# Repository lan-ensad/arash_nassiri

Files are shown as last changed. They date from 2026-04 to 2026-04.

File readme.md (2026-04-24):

# Ambilight -- Arash Nassiri

Systeme ambilight temps reel : un script Python analyse les bords d'une video, extrait les couleurs dominantes et les envoie en **UDP via WiFi** a un microcontroleur Seeed XIAO ESP32-C6 qui pilote **2 chaines** de 260 LEDs WS2812 (520 LEDs au total, 8.67 m, 60 pixels/m).

L'ESP32 et l'ordinateur de diffusion sont connectes sur un **reseau WiFi ferme** dedie. L'ESP32 est monte au milieu du bas ; les 2 chaines partent de ce point central vers la gauche et la droite, pour minimiser la longueur du fil data.

## Architecture

```
Source video (fichier ou capture HDMI via Cam Link)
    │
    ▼
Script Python (PC)  ──►  analyse des bords  ──►  traitement couleur  ──►  UDP (WiFi)
                         (zones.py)               (colors.py)             (udp_sender.py)
                                                                               │
                                                                               ▼
                                                                 Reseau WiFi ferme
                                                                               │
                                                                               ▼
                                                                      Firmware ESP32-C6
                                                                      (NeoPixelBus → WS2812)
                                                                               │
                                                                               ▼
                                                                      2 chaines de 260 LEDs
                                                                      (A = gauche, B = droite)
```

## Disposition physique

Vu depuis la position du spectateur, **face a l'ecran** :

```
         ┌─────────────────────────────────────────────────────┐
         │                     (haut : pas de ruban)           │
         │                                                     │
         │                                                     │
      ▲  │                                                     │  ▲
      │  │                                                     │  │
  150 │  │                                                     │  │ 150
  LEDs│  │                    [  E C R A N  ]                  │  │ LEDs
      │  │                                                     │  │
      │  │                                                     │  │
      │  └──────────┐                              ┌───────────┘  │
      │             │                              │              │
      └─ CHAINE A ──┤                              ├── CHAINE B ──┘
     (cote gauche)  │                              │   (cote droit)
                    │       ┌──────────────┐       │
      ◄─────────────┤       │  ESP32 + PCB │       ├─────────────►
       110 LEDs     └───────┤              ├───────┘    110 LEDs
       demi-bas             │    milieu    │            demi-bas
       gauche               └──────┬───────┘             droit
                                   │
                                   ▼
                            Alimentation 5 V
```

- **Chaine A** (260 LEDs) : cote **GAUCHE** du spectateur + demi-bas gauche
- **Chaine B** (260 LEDs) : cote **DROIT** du spectateur + demi-bas droit

Pour chaque chaine, le flux data part de l'ESP32, remonte le demi-bas (110 LEDs) puis le cote vertical (150 LEDs, du bas vers le haut).

## Chiffres cles

- **520 LEDs** WS2812 (2 chaines de 260, densite 60 px/m)
- **Alimentation** Mean Well LRS150F-5 (5 V / 30 A)
- **ESP32-C6** sortie D9 = chaine A (gauche), D10 = chaine B (droite)
- **Level shifter** SN74HCT14N (3.3 V → 5 V) entre ESP32 et rubans
- **Protocole** UDP port 4210, 2 paquets/frame (785 o chacun), ~47 KB/s a 30 fps

## Structure du projet

```
arash_nassiri/
├── readme.md               Ce fichier -- documentation generale
│
├── Firmware/               Firmware ESP32-C6 (PlatformIO)
│   └── README.md           → Installation, flashage, protocole UDP, troubleshooting firmware
│
├── script/                 Script Python (cote ordinateur)
│   └── README.md           → Installation, configuration, utilisation, troubleshooting soft
│
├── kicad/                  Electronique (schema + BOM + cablage)
│   ├── README.md           → Dimensionnement, BOM, cablage, precautions electriques
│   └── ambilight_kicad/    Projet KiCad
│
├── test_videos/            Videos de test (generees par ffmpeg)
├── run.sh                  Lancement production (fullscreen + unclutter)
└── _devis/                 Documents administratifs (devis, factures)
```

## Documentation par composant

| Composant | Documentation | Concerne |
|---|---|---|
| Electronique | [kicad/README.md](kicad/README.md) | Dimensionnement, BOM, cablage, SN74HCT14N, alimentation |
| Firmware ESP32 | [Firmware/README.md](Firmware/README.md) | PlatformIO, WiFi, flashage, protocole UDP |
| Script Python | [script/README.md](script/README.md) | OpenCV, source video, pipeline couleur, parametres |

## Demarrage rapide

Ordre recommande pour une premiere mise en route :

1. **Electronique** : lire [kicad/README.md](kicad/README.md), fabriquer / cabler la partie power + level shifter + rubans
2. **Firmware** : remplir `Firmware/src/wifi_config.h` puis flasher (voir [Firmware/README.md](Firmware/README.md))
3. **Script Python** : installer le venv et configurer `script/config.py` (voir [script/README.md](script/README.md))
4. **Lancer** : `./run.sh` depuis la racine (ou configurer le service systemd, section suivante)

Pour **tester le pipeline Python sans materiel** (loopback UDP) : voir la section Troubleshooting dans [script/README.md](script/README.md).

## Lancement automatique au boot (service systemd user)

Pour une installation permanente. Recommande quand la source video est externe (Cam Link) et `headless = True` dans `script/config.py` -- aucune session graphique requise.

`run.sh` integre deja l'attente reseau (ping de la passerelle par defaut, max 30 s) et une rotation simple des logs au demarrage : aucune modification requise avant installation.

### Prerequis a verifier dans `script/config.py`

| Parametre | Valeur recommandee | Raison |
|---|---|---|
| `headless` | `True` | Pas de session graphique sous systemd user (sauf si `DISPLAY` configure dans l'unit) |
| `terminal_preview` | `False` | Pas de terminal → les codes ANSI du preview polluent le fichier de log |
| `dry_run` | `False` | Sinon aucun paquet UDP n'est envoye |
| `video_path` / `camera_index` | source reelle | `video_path` est resolu relativement a `script/` |

IP ESP32 coherente entre `script/config.py` (`esp32_ip`) et `Firmware/src/wifi_config.h` (`LOCAL_IP_BYTES`).

### 1. Creer le service

Fichier `~/.config/systemd/user/ambilight.service` :

```ini
[Unit]
Description=Ambilight video capture and UDP send
After=network-online.target
Wants=network-online.target

[Service]
Type=simple
WorkingDirectory=/path/to/arash_nassiri
ExecStart=/path/to/arash_nassiri/run.sh
Restart=on-failure
RestartSec=5
Environment=PYTHONUNBUFFERED=1

# Double destination des logs :
#  - Fichier persistant (rotation geree par run.sh au demarrage, >10 Mo → archive timestampee, max 5 backups)
#  - Journal systemd user natif (rotation + compression gerees par journald)
StandardOutput=append:/path/to/arash_nassiri/logs/ambilight.log
StandardError=append:/path/to/arash_nassiri/logs/ambilight.log

[Install]
WantedBy=default.target
```

> Adapter les 3 chemins `/path/to/arash_nassiri/...` au chemin reel du projet. Le dossier `logs/` est cree automatiquement par `run.sh`.

### 2. Activer et demarrer

```bash
mkdir -p ~/.config/systemd/user
# (copier ambilight.service dans ce dossier)
systemctl --user daemon-reload
systemctl --user enable --now ambilight.service
```

### 3. Permettre le demarrage sans login utilisateur (lingering)

```bash
sudo loginctl enable-linger $USER
```

Sans cette ligne, le service ne demarre qu'apres connexion interactive.

### 4. Prerequis systeme

Utilisateur dans le groupe `video` pour acceder a la capture (Cam Link, webcam) :

```bash
sudo usermod -aG video $USER
# logout/login pour que le groupe prenne effet
```

### 5. Operer

```bash
# Etat
systemctl --user status ambilight.service

# Logs temps reel -- deux options equivalentes
tail -f logs/ambilight.log                          # fichier dedie
journalctl --user -u ambilight.service -f           # journal systemd

# Logs filtres
journalctl --user -u ambilight.service -p err       # erreurs uniquement
journalctl --user -u ambilight.service --since "1 hour ago"

# Cycle de vie
systemctl --user restart ambilight.service
systemctl --user stop    ambilight.service
```

### 6. Desinstaller le service

```bash
systemctl --user disable --now ambilight.service
rm -f ~/.config/systemd/user/ambilight.service
systemctl --user daemon-reload
sudo loginctl disable-linger $USER   # optionnel
```

## Reseau WiFi ferme

PC et ESP32 sur un reseau WiFi dedie (routeur/AP dedie ou hotspot du PC). Aucun trafic Internet ni autre appareil -- isolation garantit :
- Latence predictible (pas de contention)
- IP statique possible pour l'ESP32

**Config par defaut** :

| Parametre | Valeur | Fichier |
|---|---|---|
| IP ESP32 | `<IP_ESP>` | `script/config.py` + `Firmware/src/wifi_config.h` |
| Hostname ESP32 | `esp_ambilight` | `Firmware/src/wifi_config.h` |
| Port UDP | `4210` | `Firmware/src/wifi_config.h` |
| SSID / password | <SSID + PASS\> | `Firmware/src/wifi_config.h` |

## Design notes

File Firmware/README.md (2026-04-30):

# Firmware ESP32-C6

Reception des paquets UDP depuis le PC et pilotage des 2 chaines de LEDs WS2812 via NeoPixelBus (RMT).

## Prerequis

- [PlatformIO](https://platformio.org/) (extension VS Code ou CLI `pio`)
- Seeed XIAO ESP32-C6 branche en USB-C

## Configuration WiFi

Remplir les placeholders dans `src/wifi_config.h` avant de flasher :

```c
#define WIFI_SSID      "ambilight_net"       // SSID du reseau ferme
#define WIFI_PASSWORD  "mot_de_passe"

#define LOCAL_IP_BYTES    <IP_ESP>          // IP statique de l'ESP32 (format octets : a, b, c, d)
#define GATEWAY_IP_BYTES  <IP_ROUTEUR>      // IP du routeur/AP (format octets)
#define SUBNET_BYTES      255, 255, 255, 0
#define DNS_IP_BYTES      <IP_ROUTEUR>      // typiquement = gateway

#define UDP_PORT          4210
```

`LOCAL_IP_BYTES` doit correspondre a `esp32_ip` dans `script/config.py`.

## Flashage

### USB (premier flash, et recuperation)

```bash
pio run --target upload
pio device monitor    # optionnel : logs WiFi/UDP au boot
```

### OTA (flash sans fil via WiFi)

Le firmware embarque ArduinoOTA : a partir du moment ou il a ete flashe une
fois en USB, les flashs suivants peuvent se faire via le reseau.

**Pre-requis machine hote** : autoriser l'ESP32 a initier des connexions
TCP entrantes (sinon UFW/firewall bloque le retour TCP de l'OTA et `espota`
fait `Authenticating...OK` puis `No response from device`) :

```bash
sudo ufw allow from 192.168.8.50    # IP de l'ESP32 (LOCAL_IP_BYTES)
```

**Flash OTA** :

```bash
pio run -e seeed_xiao_esp32c6_ota -t upload
```

L'environnement `seeed_xiao_esp32c6_ota` defini dans `platformio.ini`
contient `--host_ip=192.168.8.202` (IP de la machine hote sur le subnet
192.168.8.x). Mettre a jour cette valeur si l'IP de la machine change
(DHCP) -- une reservation DHCP cote routeur est plus robuste a terme.

## Indicateurs visuels au boot

La 1re LED de chaque chaine sert d'indicateur :

| Couleur | Etat |
|---|---|
| **Jaune** | Connexion WiFi en cours |
| **Verte** (500 ms) | Connexion etablie, UDP en ecoute |
| **Noir** | En attente des paquets du PC |

## Protocole UDP

**2 paquets UDP par frame** (un par chaine), envoyes en rafale par le PC. Chaque paquet fait 785 octets :

| Octet | Contenu |
|---|---|
| 0 | `0xAA` (magic start) |
| 1 | `chain_id` (0 = chaine A gauche, 1 = chaine B droite) |
| 2 -- 3 | `seq_num` (uint16 big-endian) |
| 4 -- 783 | R, G, B pour chaque LED (260 x 3 = 780 octets) |
| 784 | `0x55` (magic end) |

**Taille totale par frame** : 2 x 785 = **1570 octets/frame** (vs MTU 1500 → aucune fragmentation IP au niveau paquet individuel).

**Bande passante a 30 fps** : 47 KB/s = ~376 kbps. Tres confortable meme en 2,4 GHz.

**Gestion cote firmware** (voir `src/main.cpp`) :
- `seq_num` : le firmware ignore les paquets dont le seq est plus ancien que le dernier recu (protection contre reordering UDP, rare en LAN)
- **Magic bytes** : `0xAA` / `0x55` verifies, sinon paquet ignore
- `chain_id 0 ou 1` : route le RGB data vers `stripA` (D9) ou `stripB` (D10). Chaque chaine est rafraichie des que son paquet arrive (pas de sync inter-chaines)
- `MAX_BRIGHTNESS` (defaut 230, soit ~90%) : applique une limite globale de luminosite pour proteger l'alimentation

## Pins utilises

| GPIO | Role |
|---|---|
| D9 | Signal data chaine A (gauche, 260 LEDs) |
| D10 | Signal data chaine B (droite, 260 LEDs) |

Voir [kicad/README.md](../kicad/README.md) pour le cablage complet (level shifter SN74HCT14N, resistances 330 ohm, decouplage).

## Structure des fichiers

```
Firmware/
├── platformio.ini              Configuration PlatformIO (board, framework, libs)
├── src/
│   ├── main.cpp                Reception UDP + pilotage NeoPixel (2 chaines)
│   └── wifi_config.h           Credentials WiFi + IP statique (a remplir)
├── include/                    Headers additionnels (vide par defaut)
├── lib/                        Bibliotheques locales (vide par defaut)
└── test/                       Tests (vide par defaut)
```

## Troubleshooting

### Freezes periodiques (~500 ms toutes les 2-3 s)

**Cause** : WiFi power-save du ESP32-C6 -- il wake seulement aux beacons DTIM, les paquets UDP s'accumulent sur l'AP puis sont livres en rafale.

**Fix** (deja applique dans `src/main.cpp`) : apres `WiFi.begin(...)`, desactiver le modem-sleep :
```cpp
WiFi.setSleep(false);
```

Si les freezes persistent malgre ce fix :

- **Canal WiFi encombre** -- force un canal libre (1, 6 ou 11) sur l'AP
- **Inactivite WiFi** -- ajouter apres `udp.begin(UDP_PORT)` :
  ```cpp
  esp_wifi_set_inactive_time(WIFI_IF_STA, 10);
  ```

### Aucun paquet recu (1re LED reste noire apres boot)

Verifier dans l'ordre :

1. **WiFi connecte** ? La 1re LED doit passer par jaune puis verte au boot. Si elle reste jaune, le WiFi n'a pas connecte : verifier SSID/password dans `wifi_config.h`.
2. **IP coherente** ? `LOCAL_IP_BYTES` doit etre dans le sous-reseau du routeur (pas de conflit avec un autre appareil). `esp32_ip` cote Python doit etre identique.
3. **Paquets envoyes par le PC** ? Cote PC :
   ```bash
   sudo tcpdump -i any -n 'udp port 4210'
   ```
   Doit montrer des paquets sortants du PC toutes les 33 ms (~30 fps).
4. **PC et ESP32 sur le meme reseau WiFi** ? Si le PC est en ethernet et l'ESP32 en WiFi, le routeur doit faire le pont entre les deux interfaces.

### LEDs erratiques / clignotent au hasard

Probleme electronique (GND, level shifter, longueur data). Voir [kicad/README.md](../kicad/README.md).

### Reduire la luminosite pour proteger l'alim

Dans `src/main.cpp`, ajuster :
```cpp
#define MAX_BRIGHTNESS  230   // 255 = aucune limite, 192 = 75%, 128 = 50%
```

Avec 520 LEDs et une PSU 30 A :
- 255 (100%) → 31.2 A max (depasse legerement le nominal de la PSU)
- 230 (~90%) → 28 A max (marge de securite)
- 192 (~75%) → 23 A max (tres confortable)

Un reflashage est necessaire apres modification.

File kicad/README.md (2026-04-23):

# Electronique -- Ambilight

Ce dossier contient le schema KiCad et toute la documentation electronique du projet (matiere, cablage, calculs, precautions).

Pour la partie logicielle (script Python + firmware ESP32) voir le [readme.md](../readme.md) a la racine.

## Vue d'ensemble

```
                                Mean Well LRS150F-5
                               ┌──────────────────┐
                       AC IN ──┤ L   N   ⏚        │
                               │                  │
                               │   +5V    GND     │
                               └───┬───────┬──────┘
                                   │       │
                              1000uF cap   │
                                   │       │
          ┌────────────────────────┼───────┼────────────────────────┐
          │  RAIL 5V (16AWG)       │       │  RAIL GND (16AWG)      │
          │                        │       │                        │
          │    ┌───────────────────┼───────┼──────────┐             │
          ▼    ▼                   ▼       ▼          ▼             ▼
     INJECTION 1              INJECTION 2        INJECTION 3
    (extremite gauche,        (milieu du bas,    (extremite droite,
     en haut du cote)         pres de l'ESP)     en haut du cote)
      100uF cap                100uF cap          100uF cap

    ┌─────────────────────────────────┬─────────────────────────────────┐
    │          CHAINE A (260 LEDs)    │          CHAINE B (260 LEDs)    │
    │  ┌────────────┬────────────┐    │    ┌────────────┬────────────┐  │
    │  │  GAUCHE    │  1/2 BAS   │    │    │  1/2 BAS   │  DROITE    │  │
    │  │  (150)     │  gauche    │    │    │  droite    │  (150)     │  │
    │  │  bas→haut  │  (110)     │    │    │  (110)     │  bas→haut  │  │
    │  │            │  gauche ←  │◄DIN│DIN►│  → droite  │            │  │
    │  │   DOUT ←── │ ← ─────────│    │    │────────── →│ ──► DOUT   │  │
    │  └────────────┴────────────┘    │    └────────────┴────────────┘  │
    └─────────────────────────────────┴─────────────────────────────────┘
                                 ▲       ▲
                    330 ohm ─────┤       ├──── 330 ohm
                                 │       │
                         data 5V │       │ data 5V (< 30 cm, 22AWG)
                          pin 4  │       │ pin 10
                    ┌────────────┴───────┴─────────────┐
                    │  SN74HCT14N (hex Schmitt inv.)   │
                    │                                  │
                    │  Chaine A : pin 1 → pin 2,       │
                    │             pin 3 → pin 4        │
                    │  Chaine B : pin 13 → pin 12,     │
                    │             pin 11 → pin 10      │
                    │                                  │
                    │  VCC = pin 14 (+5V) + 100nF      │
                    │  GND = pin 7                     │
                    │  entrees NC (5, 9) → GND         │
                    └──────▲──────────────▲────────────┘
                           │ pin 1        │ pin 13
                           │ data A 3.3V  │ data B 3.3V
                    ┌──────┴──────────────┴────────────┐
                    │  XIAO ESP32-C6                   │
                    │     D9 ─(chaine A gauche)        │
                    │    D10 ─(chaine B droite)        │
                    │    USB ← 5V (alim seule,         │
                    │          chargeur ou powerbank)  │
                    │    WiFi ◄─── UDP (port 4210)     │
                    └─────────────────────▲────────────┘
                                          │ reseau WiFi ferme dedie
                                          │
                                   ┌──────┴───────┐
                                   │  PC (Python) │
                                   │  udp_sender  │
                                   └──────────────┘
```

## Dimensionnement

### Installation

| Cote | Longueur |
|---|---|
| Bas | 368 cm |
| Droite | 250 cm |
| Gauche | 250 cm |
| **Total** | **868 cm = 8.68 m** |

### LEDs

Densite du ruban : **60 pixels/m**

| Cote | Longueur | LEDs |
|---|---|---|
| Bas | 3.67 m | 3.67 x 60 = **220** (110 + 110, symetrique) |
| Droite | 2.50 m | 2.50 x 60 = **150** |
| Gauche | 2.50 m | 2.50 x 60 = **150** |
| **Total** | **8.67 m** | **520 LEDs** |

Le bas est ramene de 221 a **220 LEDs** pour une **repartition symetrique** (110 par demi-cote). Le gain physique est de 1,67 cm, negligeable visuellement.

### Repartition en 2 chaines

L'ESP32 est positionne au **milieu du bas**. Deux chaines de LEDs partent de ce point central vers l'exterieur, pilotees chacune par un GPIO different :

| Chaine | GPIO | Trajet | LEDs |
|---|---|---|---|
| **A** (gauche) | D9 | demi-bas milieu → gauche, puis cote gauche bas → haut | 110 + 150 = **260** |
| **B** (droite) | D10 | demi-bas milieu → droite, puis cote droit bas → haut | 110 + 150 = **260** |

Avantages vs une seule chaine de 521 LEDs :
- Fil data 10 fois plus court (< 30 cm au lieu de ~1,85 m vers un coin)
- Rafraichissement LED plus rapide (2 chaines en parallele, ~260 LEDs chacune au lieu de 521)
- Ligne data moins sensible aux perturbations

### Puissance

Chaque LED WS2812 consomme au maximum 60 mA a 5 V (20 mA par canal R, G, B a pleine intensite).

| Scenario | Courant par LED | Courant total | Puissance (5 V) |
|---|---|---|---|
| Maximum (blanc 100%) | 60 mA | 520 x 60 mA = **31.2 A** | **156.0 W** |
| Utilisation typique ambilight (~30%) | ~20 mA | 520 x 20 mA = **10.4 A** | **52.0 W** |

**Alimentation choisie** : 1x Mean Well LRS150F-5 -- 5 V / 30 A (150 W).

> 30 A couvre le maximum theorique (31.2 A) a ~96%. En pratique l'ambilight ne
> depasse jamais le blanc pur simultane sur toutes les LEDs ; le budget typique
> (~10 A) laisse une large marge. Si un contenu pousse ponctuellement au-dela,
> la LRS150F-5 tolere des pics courts a 110% (33 A).

## Cablage de l'ESP32-C6

| Broche ESP32-C6 | Connexion | Note |
|---|---|---|
| USB-C ou pad 5V | 5 V depuis la PSU via Wago ou regulateur | Alim seule — les donnees passent par WiFi |
| D9 | Level shifter IN chaine A (pin 1) | Signal data chaine A (gauche, 260 LEDs) |
| D10 | Level shifter IN chaine B (pin 13) | Signal data chaine B (droite, 260 LEDs) |
| GND | GND commun (PSU + level shifter) | **Obligatoire** |
| WiFi (integre) | Reseau ferme dedie | Reception UDP du PC |

> **Decouplage ESP32** : placer 22 uF electrolytique + 100 nF ceramique en parallele sur le rail 5 V au plus pres du VBUS, pour filtrer le bruit HF genere par les 520 LEDs qui commutent a 800 kHz.

## Cablage du level shifter SN74HCT14N

Boitier DIP-14 (6 inverseurs Schmitt trigger independants). On utilise **4 portes** (2 cascades de 2 inverseurs), une cascade par chaine. 2 portes restent inutilisees.

```
           ┌───U───┐
    1A  ──1┤       ├14──  VCC (+5 V)
    1Y  ──2┤       ├13──  6A  ← D10 (chaine B, 3.3V)
    2A  ──3┤       ├12──  6Y
    2Y  ──4┤       ├11──  5A
    3A  ──5┤       ├10──  5Y  → 330 ohm → chaine B DIN (5V)
    3Y  ──6┤       ├9──── 4A  (NC → GND)
    GND ──7┤       ├8──── 4Y  (NC)
           └───────┘
```

### Chaine A (gauche) -- cascade inverseurs 1 et 2

| Broche | Role | Connexion |
|---|---|---|
| 1 (1A) | Entree inverseur 1 | Signal 3.3 V depuis ESP32 **D9** |
| 2 (1Y) | Sortie inverseur 1 | Relier a la broche 3 |
| 3 (2A) | Entree inverseur 2 | Relier a la broche 2 |
| 4 (2Y) | Sortie inverseur 2 (5 V) | Resistance 330 ohm puis DIN chaine A |

### Chaine B (droite) -- cascade inverseurs 6 et 5

| Broche | Role | Connexion |
|---|---|---|
| 13 (6A) | Entree inverseur 6 | Signal 3.3 V depuis ESP32 **D10** |
| 12 (6Y) | Sortie inverseur 6 | Relier a la broche 11 |
| 11 (5A) | Entree inverseur 5 | Relier a la broche 12 |
| 10 (5Y) | Sortie inverseur 5 (5 V) | Resistance 330 ohm puis DIN chaine B |

### Portes inutilisees (inverseurs 3 et 4)

| Broche | Role | Connexion |
|---|---|---|
| 5 (3A), 9 (4A) | Entrees inutilisees | **Obligatoire : relier a GND** |
| 6 (3Y), 8 (4Y) | Sorties inutilisees | Laisser en l'air |

### Alimentation

| Broche | Connexion |
|---|---|
| 14 (VCC) | +5 V depuis la PSU |
| 7 (GND) | GND commun avec PSU et ESP32 |

**Decouplage** : condensateur 100 nF ceramique (marquage "104") entre broche 14 et broche 7, **au plus pres du chip** (pattes < 5 mm).

## Fichiers KiCad

Le projet KiCad complet est dans [ambilight_kicad/](ambilight_kicad/).

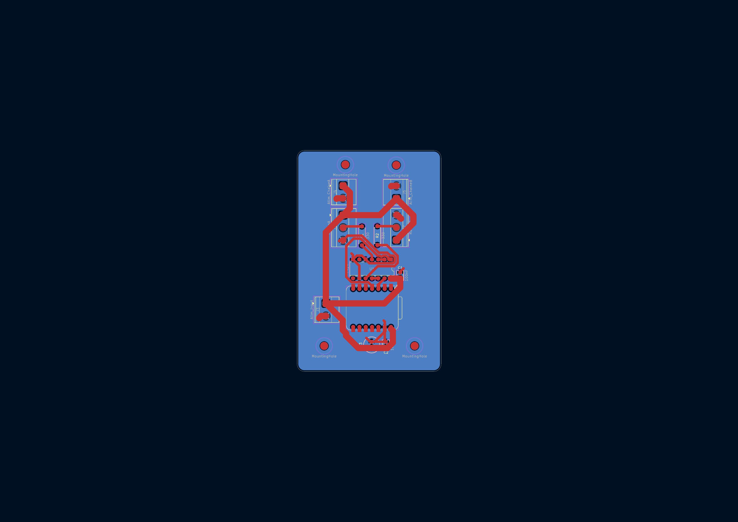
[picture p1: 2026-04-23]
kicad/ambilight_kicad/layout.jpg

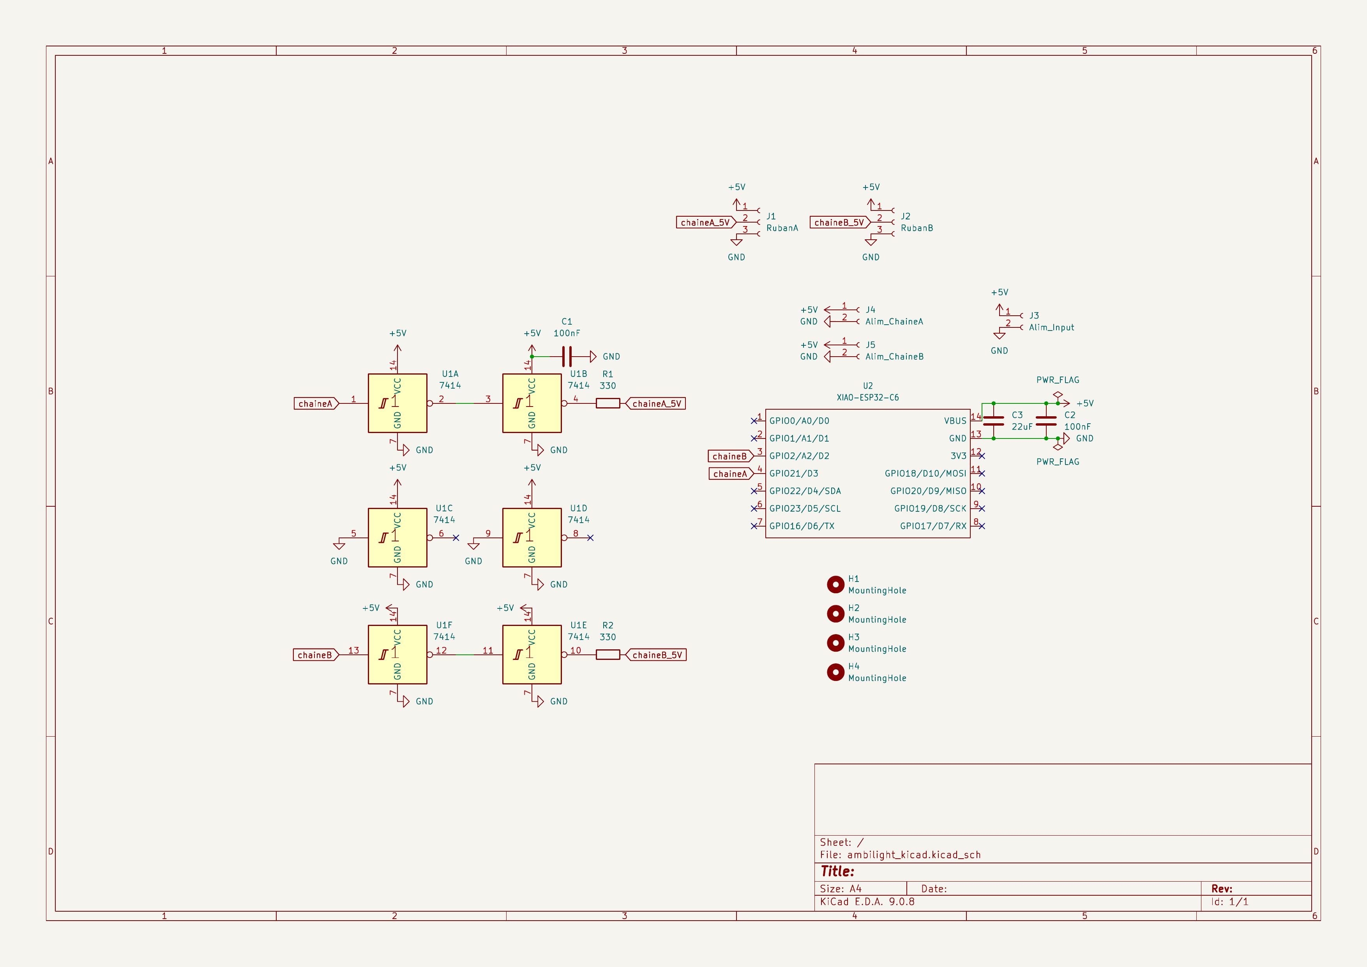
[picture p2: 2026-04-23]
kicad/ambilight_kicad/schem.jpg

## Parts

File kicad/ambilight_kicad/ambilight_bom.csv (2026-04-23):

Reference | Qty | Value | DNP | Exclude from BOM | Exclude from Board | Footprint | Datasheet
C1,C2 | 2 | 100nF |  |  |  | Capacitor_THT:C_Disc_D3.8mm_W2.6mm_P2.50mm | ~
C3 | 1 | 22uF |  |  |  | Capacitor_THT:C_Radial_D6.3mm_H7.0mm_P2.50mm | ~
H1,H2,H3,H4 | 4 | MountingHole |  | Excluded from BOM |  | MountingHole:MountingHole_3.2mm_M3 | ~
J1 | 1 | RubanA |  |  |  | TerminalBlock_Phoenix:TerminalBlock_Phoenix_MKDS-1,5-3-5.08_1x03_P5.08mm_Horizontal | ~
J2 | 1 | RubanB |  |  |  | TerminalBlock_Phoenix:TerminalBlock_Phoenix_MKDS-1,5-3-5.08_1x03_P5.08mm_Horizontal | ~
J3 | 1 | Alim_Input |  |  |  | TerminalBlock_Phoenix:TerminalBlock_Phoenix_MKDS-1,5-2-5.08_1x02_P5.08mm_Horizontal | ~
J4 | 1 | Alim_ChaineA |  |  |  | TerminalBlock_Phoenix:TerminalBlock_Phoenix_MKDS-1,5-2-5.08_1x02_P5.08mm_Horizontal | ~
J5 | 1 | Alim_ChaineB |  |  |  | TerminalBlock_Phoenix:TerminalBlock_Phoenix_MKDS-1,5-2-5.08_1x02_P5.08mm_Horizontal | ~
R1,R2 | 2 | 330 |  |  |  | Resistor_THT:R_Axial_DIN0207_L6.3mm_D2.5mm_P7.62mm_Horizontal | ~
U1 | 1 | 7414 |  |  |  | Package_DIP:DIP-14_W7.62mm
U2 | 1 | XIAO-ESP32-C6 |  |  |  | XIAO:XIAO-ESP32C6-DIP

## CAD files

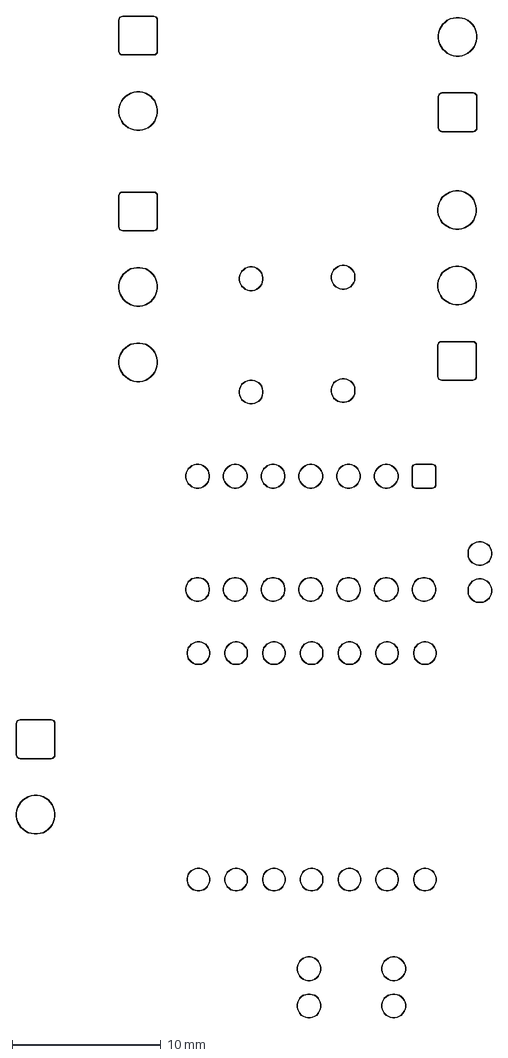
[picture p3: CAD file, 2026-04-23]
kicad/ambilight_kicad/gerber/ambilight_kicad-B_Cu.dxf
32.0 x 67.4 mm

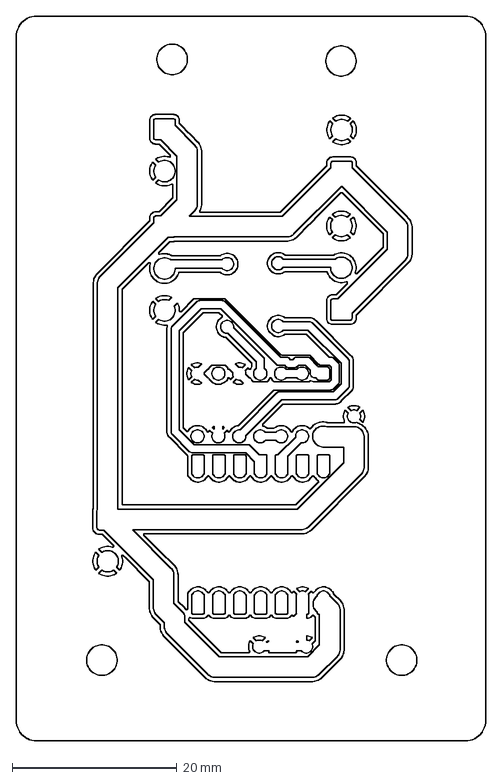
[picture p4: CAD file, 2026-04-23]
kicad/ambilight_kicad/gerber/ambilight_kicad-F_Cu.dxf
57.0 x 88.0 mm

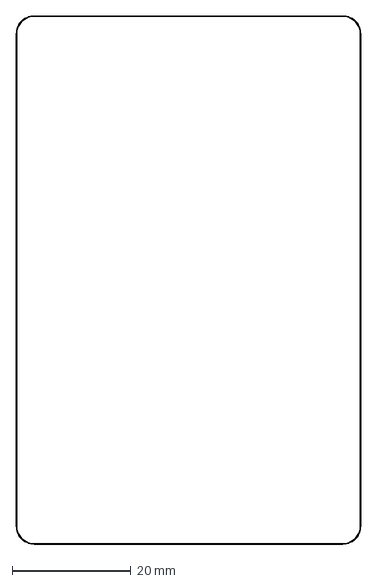
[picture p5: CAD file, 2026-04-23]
kicad/ambilight_kicad/gerber/ambilight_kicad-Edge_Cuts.dxf
58.0 x 89.0 mm

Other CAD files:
kicad/ambilight_kicad/gerber/ambilight_kicad-B_Mask.dxf
kicad/ambilight_kicad/gerber/ambilight_kicad-B_Paste.dxf
kicad/ambilight_kicad/gerber/ambilight_kicad-B_Silkscreen.dxf
kicad/ambilight_kicad/gerber/ambilight_kicad-F_Mask.dxf
kicad/ambilight_kicad/gerber/ambilight_kicad-F_Paste.dxf
kicad/ambilight_kicad/gerber/ambilight_kicad-F_Silkscreen.dxf

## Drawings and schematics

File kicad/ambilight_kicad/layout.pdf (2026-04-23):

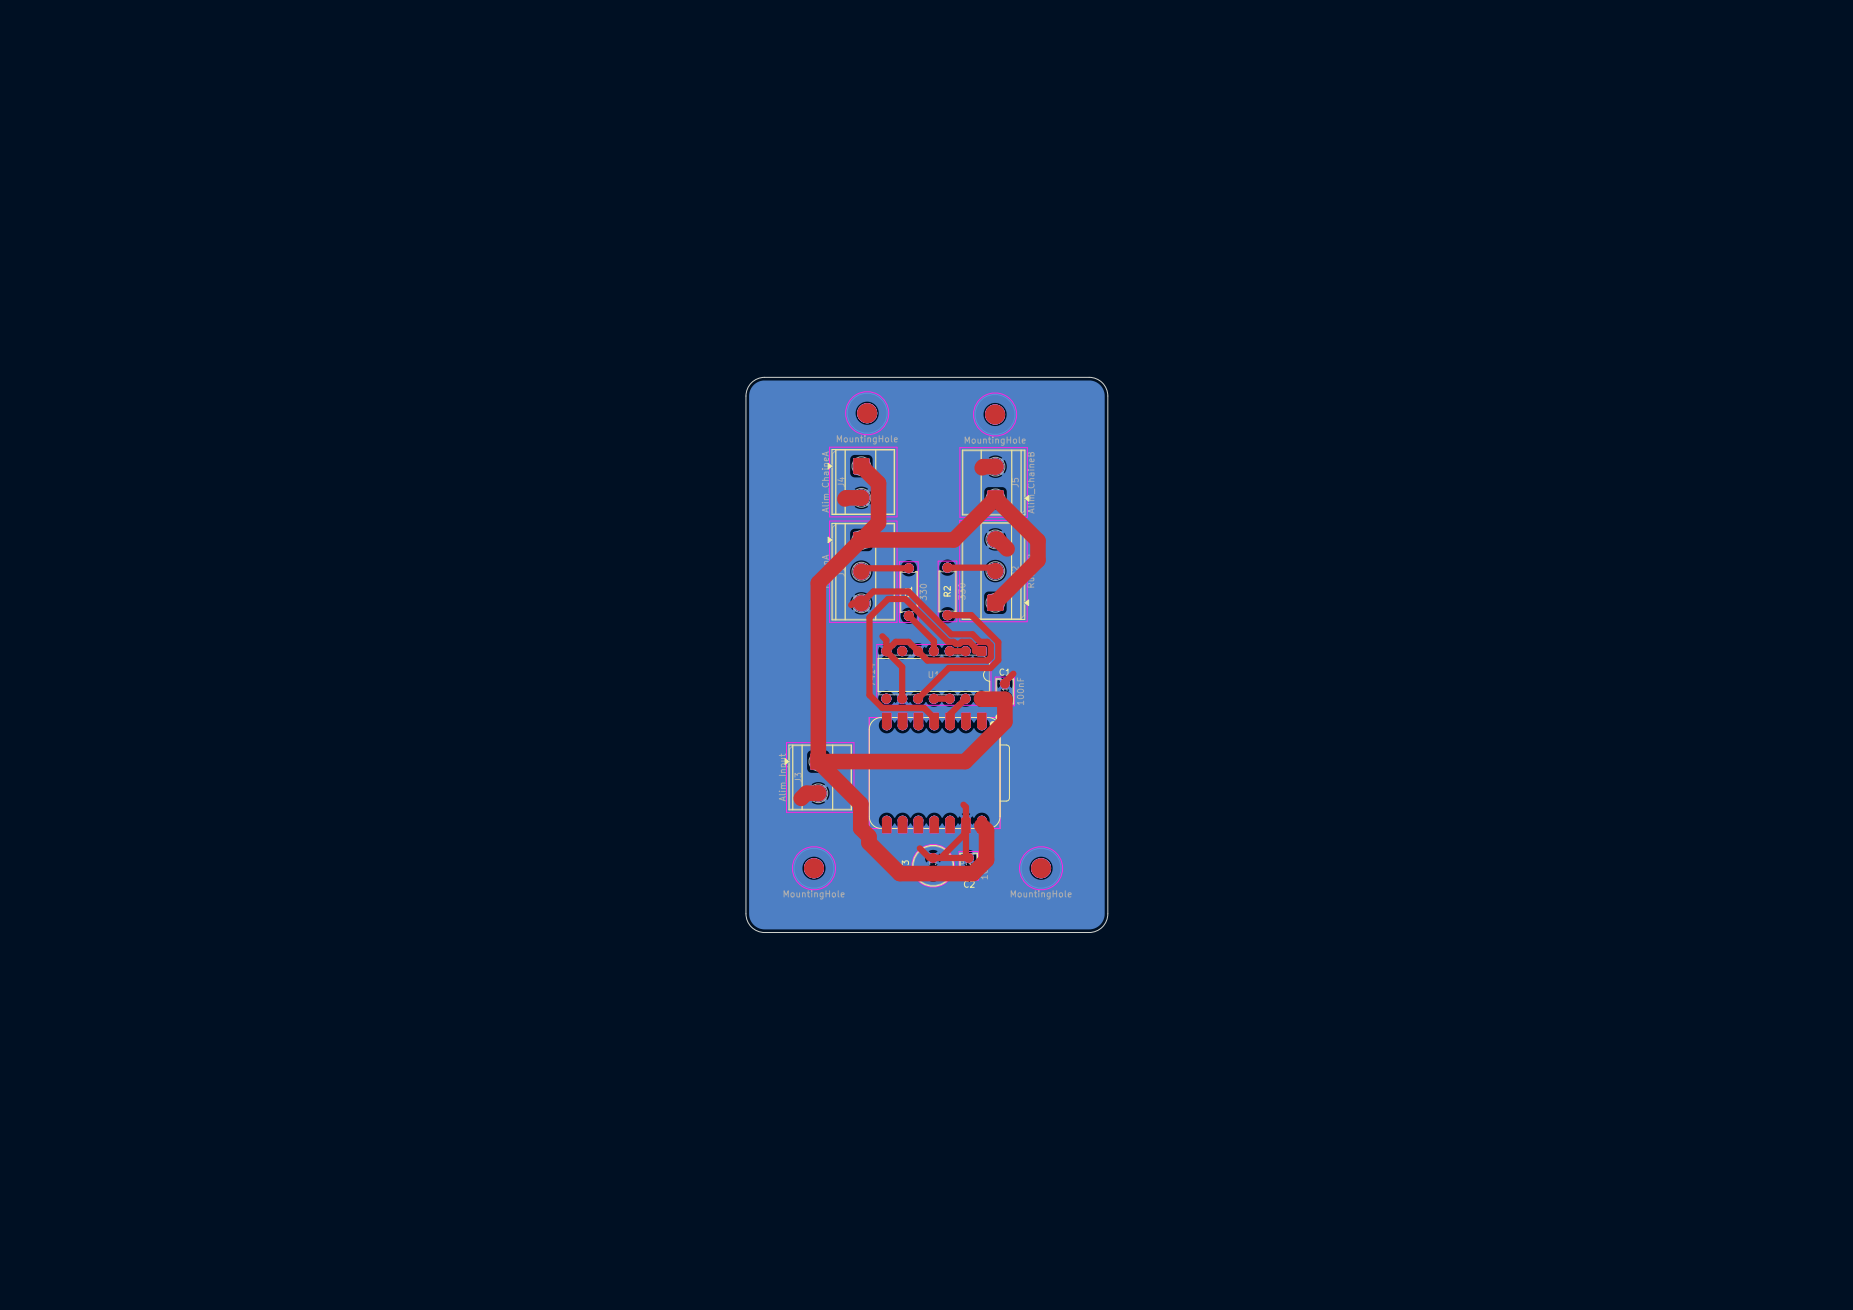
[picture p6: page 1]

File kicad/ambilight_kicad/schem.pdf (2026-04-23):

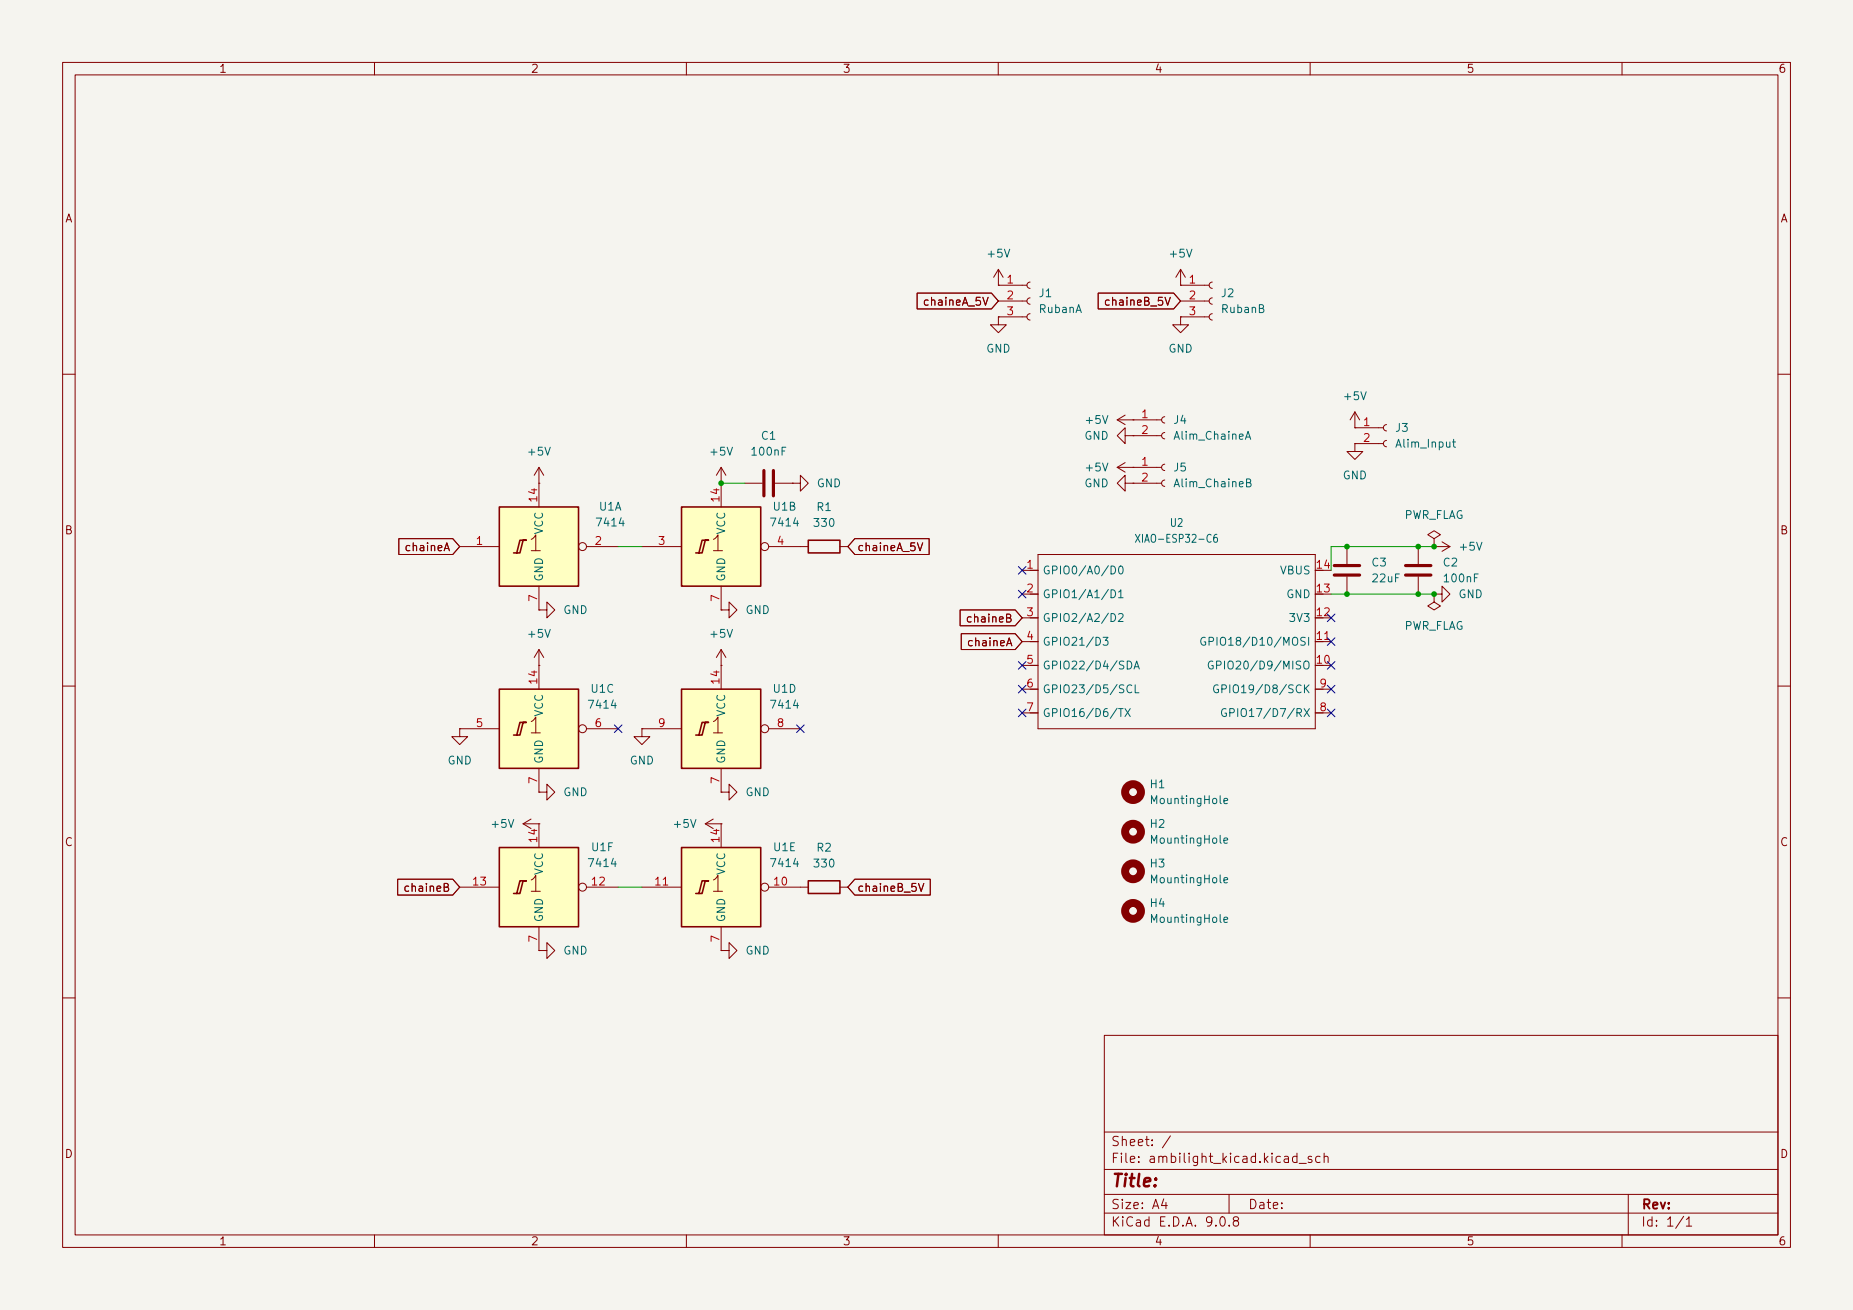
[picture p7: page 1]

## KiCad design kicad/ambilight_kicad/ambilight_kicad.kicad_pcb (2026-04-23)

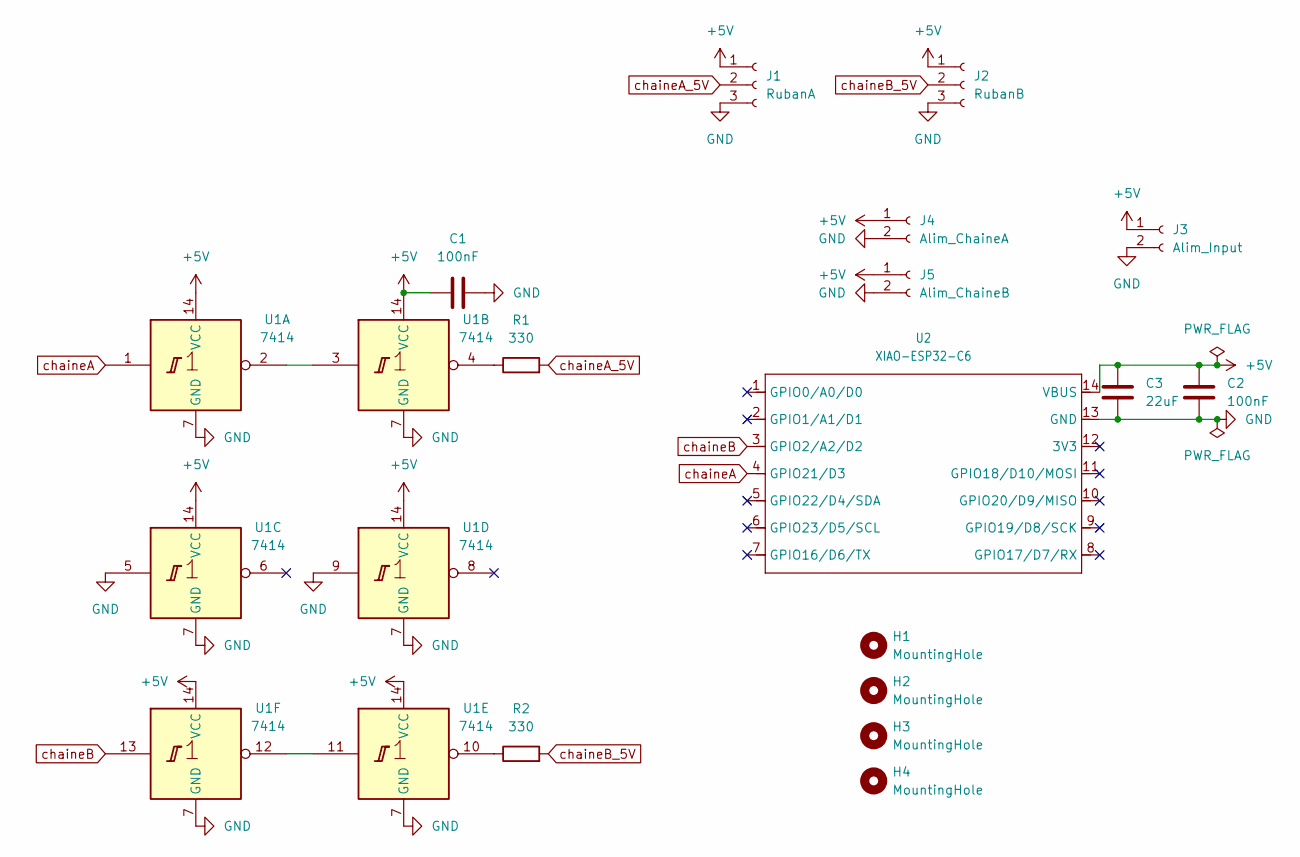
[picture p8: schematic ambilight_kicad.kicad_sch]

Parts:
C1, C2: 100nF; C_Disc_D3.8mm_W2.6mm_P2.50mm
C3: 22uF; C_Radial_D6.3mm_H7.0mm_P2.50mm
H1, H2, H3, H4: MountingHole; MountingHole_3.2mm_M3
J1: RubanA; TerminalBlock_Phoenix_MKDS-1,5-3-5.08_1x03_P5.08mm_Horizont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
J2: RubanB; TerminalBlock_Phoenix_MKDS-1,5-3-5.08_1x03_P5.08mm_Horizont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
J3: Alim_Input; TerminalBlock_Phoenix_MKDS-1,5-2-5.08_1x02_P5.08mm_Horizont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
J4: Alim_ChaineA; TerminalBlock_Phoenix_MKDS-1,5-2-5.08_1x02_P5.08mm_Horizont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
J5: Alim_ChaineB; TerminalBlock_Phoenix_MKDS-1,5-2-5.08_1x02_P5.08mm_Horizont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
R1, R2: 330; R_Axial_DIN0207_L6.3mm_D2.5mm_P7.62mm_Horizontal
U1: 7414; DIP-14_W7.62mm
U2: XIAO-ESP32-C6; XIAO-ESP32C6-DIP

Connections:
+5V: C1.1, C2.1, C3.1, J1.1, J2.1, J3.1, J4.1, J5.1, U1.14 (VCC), U2.14 (VBUS)
GND: C1.2, C2.2, C3.2, J1.3, J2.3, J3.2, J4.2, J5.2, U1.5, U1.7 (GND), U1.9, U2.13 (GND)
unnamed: R1.1, U1.4
unnamed: R2.1, U1.10
unnamed: U1.2, U1.3
unnamed: U1.11, U1.12
chaineA: U1.1, U2.4 (GPIO21/D3)
chaineA_5V: J1.2, R1.2
chaineB: U1.13, U2.3 (GPIO2/A2/D2)
chaineB_5V: J2.2, R2.2

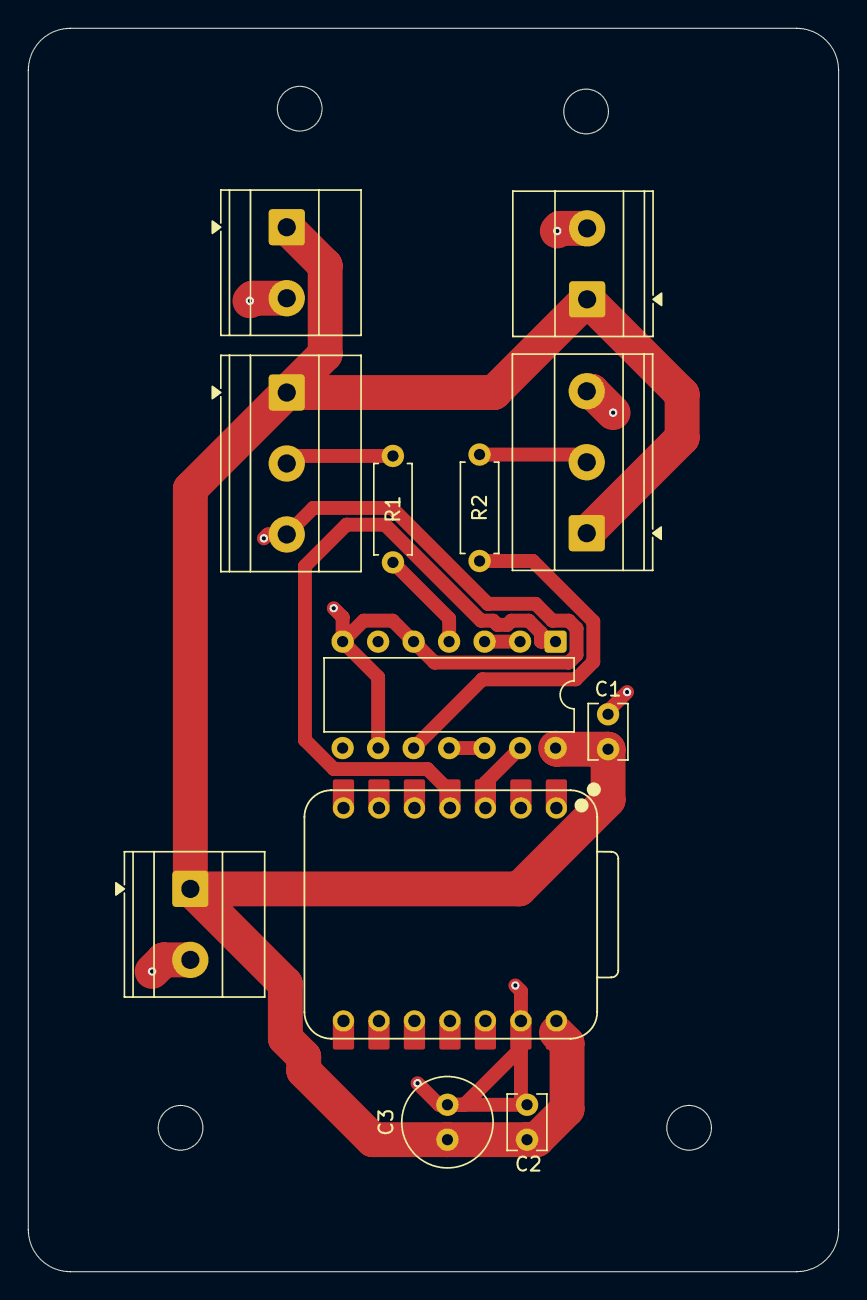
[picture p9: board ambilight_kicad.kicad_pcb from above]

Board: 2 copper layers, 58.0 x 89.0 mm, 16 parts (0 on the bottom side), 10 nets.

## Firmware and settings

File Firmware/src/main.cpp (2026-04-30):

#include <ArduinoOTA.h>
#include <NeoPixelBus.h>
#include <WiFi.h>
#include <WiFiUdp.h>

#include "wifi_config.h"

// --- Config LEDs (doit correspondre a config.py) ---
// L'ESP32 est monte au milieu du bas. Deux chaines partent de ce point
// central vers l'exterieur pour reduire la longueur du fil data.
//   Chaine A (gauche) : demi-bas gauche (110) + cote gauche (150) = 260
//   Chaine B (droite) : demi-bas droite (110) + cote droit  (150) = 260
#define LEDS_BOTTOM     220
#define LEDS_RIGHT      150
#define LEDS_LEFT       150
#define HALF_BOTTOM     (LEDS_BOTTOM / 2)
#define LEDS_CHAIN_A    (HALF_BOTTOM + LEDS_LEFT)                  // 260
#define LEDS_CHAIN_B    ((LEDS_BOTTOM - HALF_BOTTOM) + LEDS_RIGHT) // 260

#define DATA_PIN_A      D3    // chaine A → J1 (cote gauche, GPIO21)
#define DATA_PIN_B      D2    // chaine B → J2 (cote droit, GPIO2)

// --- Protocole UDP (doit correspondre a udp_sender.py) ---
//   octet 0      : 0xAA (magic start)
//   octet 1      : chain_id (0 = A, 1 = B)
//   octets 2-3   : seq_num (uint16 big-endian)
//   octets 4..N  : RGB data (n_leds x 3)
//   octet N+1    : 0x55 (magic end)
#define START_BYTE      0xAA
#define END_BYTE        0x55
#define HEADER_LEN      4

#define PACKET_LEN_A    (HEADER_LEN + LEDS_CHAIN_A * 3 + 1)  // 785
#define PACKET_LEN_B    (HEADER_LEN + LEDS_CHAIN_B * 3 + 1)  // 785
#define MAX_PACKET_LEN  800

// --- Limite de luminosite (protection alimentation) ---
// 255 = aucune limite, 192 = 75% (~23A max), 128 = 50% (~15.6A max)
#define MAX_BRIGHTNESS  255

// --- Objets globaux ---
NeoPixelBus<NeoGrbFeature, NeoEsp32BitBangWs2812xMethod> stripA(LEDS_CHAIN_A, DATA_PIN_A);
NeoPixelBus<NeoGrbFeature, NeoEsp32BitBangWs2812xMethod> stripB(LEDS_CHAIN_B, DATA_PIN_B);

WiFiUDP udp;
uint8_t packet_buf[MAX_PACKET_LEN];

uint16_t last_seq_a = 0;
uint16_t last_seq_b = 0;
bool     seq_a_init = false;
bool     seq_b_init = false;

// Reset du tracking de sequence apres ce delai de silence : permet de repartir
// proprement quand le sender est arrete puis relance (seq cote Python repart a 0).
#define SESSION_TIMEOUT_MS  500
uint32_t last_packet_ms = 0;

// Flag pose pendant un flash OTA : suspend la reception UDP + Show() pour
// liberer le CPU et eviter que les interrupts off du bit-bang WS2812
// parasitent la reception du firmware.
volatile bool ota_in_progress = false;

// -----------------------------------------------------------
// Boot indicator sur la 1re LED des deux chaines
static void show_boot_indicator(RgbColor color) {
    stripA.SetPixelColor(0, color);
    stripB.SetPixelColor(0, color);
    stripA.Show();
    stripB.Show();
}

// -----------------------------------------------------------
// Ecriture d'une chaine a partir du buffer RGB (applique MAX_BRIGHTNESS)
// Template pour servir les 2 canaux RMT avec le meme code.
template <typename TStrip>
static void apply_chain(TStrip& strip, int n_leds, const uint8_t* rgb_data) {
    for (int i = 0; i < n_leds; i++) {
        uint8_t r = (uint16_t)rgb_data[i * 3 + 0] * MAX_BRIGHTNESS / 255;
        uint8_t g = (uint16_t)rgb_data[i * 3 + 1] * MAX_BRIGHTNESS / 255;
        uint8_t b = (uint16_t)rgb_data[i * 3 + 2] * MAX_BRIGHTNESS / 255;
        strip.SetPixelColor(i, RgbColor(r, g, b));
    }
}

// -----------------------------------------------------------
// Gere le wraparound 16 bits : diff signe > 0 → plus recent
static bool seq_is_newer(uint16_t seq, uint16_t last) {
    return (int16_t)(seq - last) > 0;
}

// -----------------------------------------------------------
void setup() {
    Serial.begin(115200);
    delay(100);

    stripA.Begin();
    stripB.Begin();
    stripA.ClearTo(RgbColor(0, 0, 0));
    stripB.ClearTo(RgbColor(0, 0, 0));
    stripA.Show();
    stripB.Show();

    // Indicateur boot : 1re LED jaune pendant connexion WiFi
    show_boot_indicator(RgbColor(64, 64, 0));

    WiFi.mode(WIFI_STA);
    WiFi.setHostname(WIFI_HOSTNAME);
    WiFi.config(
        IPAddress(LOCAL_IP_BYTES),
        IPAddress(GATEWAY_IP_BYTES),
        IPAddress(SUBNET_BYTES),
        IPAddress(DNS_IP_BYTES)
    );
    WiFi.begin(WIFI_SSID, WIFI_PASSWORD);
    WiFi.setSleep(false);  // desactive modem-sleep : sinon freezes ~500ms tous les 2-3s

    Serial.print("WiFi : connexion a ");
    Serial.println(WIFI_SSID);

    // Garde-fou : si la connexion ne vient pas dans la limite, on reboote.
    // Couvre routeur cassé, credentials errones, conflit d'IP, etc.
    const uint32_t connect_start       = millis();
    const uint32_t CONNECT_TIMEOUT_MS  = 90000;

    while (WiFi.status() != WL_CONNECTED) {
        if (millis() - connect_start > CONNECT_TIMEOUT_MS) {
            Serial.println();
            Serial.println("WiFi : timeout, reboot");
            delay(100);
            ESP.restart();
        }
        delay(250);
        Serial.print(".");
    }

    Serial.println();
    Serial.print("WiFi connecte. IP : ");
    Serial.print(WiFi.localIP());
    Serial.print(" (hostname : ");
    Serial.print(WIFI_HOSTNAME);
    Serial.println(")");

    // Indicateur connexion OK : 1re LED verte 500 ms puis noir
    show_boot_indicator(RgbColor(0, 64, 0));
    delay(500);
    stripA.ClearTo(RgbColor(0, 0, 0));
    stripB.ClearTo(RgbColor(0, 0, 0));
    stripA.Show();
    stripB.Show();

    udp.begin(UDP_PORT);
    Serial.print("UDP : ecoute sur le port ");
    Serial.println(UDP_PORT);

    // --- ArduinoOTA (flash sans fil) ---
    ArduinoOTA.setHostname(WIFI_HOSTNAME);
    ArduinoOTA.setPassword("ambilight");
    ArduinoOTA.onStart([]() {
        ota_in_progress = true;
        // Eteindre les rubans : les Show() bit-bang desactivent les
        // interrupts et perturbent la reception du firmware OTA.
        stripA.ClearTo(RgbColor(0, 0, 0));
        stripB.ClearTo(RgbColor(0, 0, 0));
        stripA.Show();
        stripB.Show();
        Serial.println("OTA: start");
    });
    ArduinoOTA.onEnd([]() {
        Serial.println("OTA: end (reboot)");
    });
    ArduinoOTA.onError([](ota_error_t e) {
        ota_in_progress = false;
        Serial.printf("OTA: error %u\n", e);
    });
    ArduinoOTA.begin();
    Serial.println("OTA pret");
}

// -----------------------------------------------------------
void loop() {
    ArduinoOTA.handle();
    if (ota_in_progress) return;  // suspendre tout pendant le flash

    int packet_size = udp.parsePacket();
    if (packet_size <= 0) return;

    if (packet_size > MAX_PACKET_LEN) {
        udp.flush();
        return;
    }

    int read = udp.read(packet_buf, packet_size);
    if (read < HEADER_LEN + 1) return;

    // Verification magic bytes
    if (packet_buf[0] != START_BYTE) return;
    if (packet_buf[read - 1] != END_BYTE) return;

    uint32_t now = millis();
    if (now - last_packet_ms > SESSION_TIMEOUT_MS) {
        seq_a_init = false;
        seq_b_init = false;
    }
    last_packet_ms = now;

    uint8_t  chain_id = packet_buf[1];
    uint16_t seq      = ((uint16_t)packet_buf[2] << 8) | packet_buf[3];

    if (chain_id == 0) {
        if (read != PACKET_LEN_A) return;
        if (seq_a_init && !seq_is_newer(seq, last_seq_a)) return;
        last_seq_a = seq;
        seq_a_init = true;

        apply_chain(stripA, LEDS_CHAIN_A, packet_buf + HEADER_LEN);
        stripA.Show();
    } else if (chain_id == 1) {
        if (read != PACKET_LEN_B) return;
        if (seq_b_init && !seq_is_newer(seq, last_seq_b)) return;
        last_seq_b = seq;
        seq_b_init = true;

        apply_chain(stripB, LEDS_CHAIN_B, packet_buf + HEADER_LEN);
        stripB.Show();
    }
}
